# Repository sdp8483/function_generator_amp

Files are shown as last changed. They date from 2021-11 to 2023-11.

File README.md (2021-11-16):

# KiCAD Directory Structure

Directory structure for starting new projects in KiCAD. Based off Hackaday article: https://hackaday.com/2017/05/18/kicad-best-practises-library-management/

## Directory Outline
- [`~/pcb/`](pcb) is for KiCAD desinge files. When starting a new KiCAD project in this directory be sure to uncheck *Create a new direcotry for the project* in the **Create New Project** window.
- [`~/firmware/`](firmware) is for firmware souce code and binaries.
- [`~/enclosure/`](enclosure) is for mechanical CAD design files for the encloser or box. Create seperate directories for `.stl` or other files for 3d printing for easy accesss.

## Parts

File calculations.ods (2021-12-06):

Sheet: General
Function Generator Amplifier Calculaitons
based on the following design guide: https://www.circuitbasics.com/tda2050-diy-amplifier-build-guide/
TDA2030 Limits
Minumum Gain | 24 | dB
Supply Voltage | ±18 | V | 36
Peak Output Current | 3.5 | A
Max Power Dissipation | 20 | W
Desired Output
Output Voltage | 10 | Vrms
Output Voltage | 28.3 | Vp-p
Peak Output Voltage
Load Impedance, Rl | 75 | Ω
Power Output Average, Po | 7.66139999998758 | W
Peak Output Voltage, Vp | 33.9 | V
Maximum Supply Voltage Needed by the Amplifier
Peak Output Voltage, Vp | 33.9 | V
TDA2030 Voltage Drop, Vd | 4 | V
Xformer Voltage Increase when unloaded, Vr | 6%
Variation in mains voltage, Vvm | 10%
Max Supply Voltage, Vs | 44.2 | V
Maximum Supply Voltage Provided by a Transformer
Transformer Voltage Rating, Vt | 12 | VAC
Rectified Voltage Increse Factor, Vd | 1.41
Variation in mains voltage, Vvm | 10%
Xformer Voltage Increase when unloaded, Vr | 6%
Maximum Supply Voltage, Vs | 19.7 | V
Amplifier Output Power from a Transformers Maximum Supply Voltage
Output Power, Po | 1.1 | W
Maximum xformer supply voltage, Vcc | 19.7 | V
TDA2030 Voltage Drop, Vd | 4 | V
Xformer Voltage Increase when unloaded, Vr | 6%
Variation in mains voltage, Vvm | 10%
Load Impedance, Rl | 75 | Ω
Transformer Power Needed by the Amplifier
Maximum xformer supply voltage, Vcc | 19.7 | V
Peak Output Voltage, Vp | 33.9 | V
TDA2030 Quiescent draion current, Iq | 0.06 | A
Load Impedance, Rl | 75 | Ω
Total Power, Psupply | 8.0 | W
Transformer VA Rating
Rating Factor | 1.5
Transformer VA | 12.1 | VA
Maximum Power Dissipation
Maximum xformer supply voltage, Vcc | 19.7 | V
Load Impedance, Rl | 75 | Ω
Max Power Dissipation, Pd | 1.1 | W
Maximum Thermal Resistance of the Heat Sink
Max Junction Temperature, Tjmax | 150 | C
Ambient Temperature, Tamb | 25 | C
Junction to Case thermal resistance, Rjc | 3 | C/W
Case to heatsink thermal resistance, Rch | 0.12 | C/W
Max Power Dissipation, Pd | 1.1 | W
Max Thermal Resistance of the Heat Sink, Rh | 115.7 | C/W

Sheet: Transformer
Transformer Settings
Output Voltage | 20 | VAC
Output Rating | 20 | VA
Unloaded Voltage | 12%
Power Factor | 1.5
Calculated Max Power | 13.3 | W
Rectified Voltage
Rectifcation Factor | 1.41
Mains Voltage Variation | 10%
Max Rectified Voltage | 34.8 | VDC
 | 17.4 | ±VDC
Ripple Voltage
Max Load Current | 1.5 | A
Mains Frequeuncy | 60 | Hz
Total Capacitance Per Rail | 6600 | uF
Ripple Voltage | 1.89 | V

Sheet: Amplifier
Minimum Gain |  |  |  | SI Prefixes
Input Voltage, Vin | 0.5 | V |  | symbol | 10^n
Load Impedance | 6 | Ω |  | k | 1000
Output Power | 14 | W |  | m | 0.001
Gain | 18.3 |  |  | μ | 0.000001
Gain, db | 25.3 | db |  | n | 0.000000001
 |  |  |  | p | 1E-12
Gain
R3 | 22 | kΩ
R2 | 1000 | Ω
Gain | 23.0 | V/V
 | 27.2 | dB
Input Signal | 0.184 | V
Output Signal | 4.243 | V
 | 6.000 | Vrms
Balance Input Bias Current
R12 | 1 | kΩ
R1 | 21 | kΩ
R3 | 22 | kΩ
R3 : (R1 + R3) | 1
Input High Pass Filter
C5 | 2.2 | uF
R1 | 21 | kΩ
Cutoff Frequency, Fc | 3.4 | Hz
Feedback Loop High Pass Filter
R2 | 1000 | Ω
C6 | 220 | uF
Cutoff Frequency, Fc | 0.7 | Hz
Input to Feedback Fc Ratio | 4.8
Input Low Pass Filter
R11 | 1 | kΩ
R12 | 1 | kΩ
C19 | 220 | pF
Cutoff Frequency, Fc | 362 | kHz
Zorbel Network |  |  | c
R4 | 10 | Ω
C11 | 100 | nF
Cutoff Frequency, Fc | 159 | kHz

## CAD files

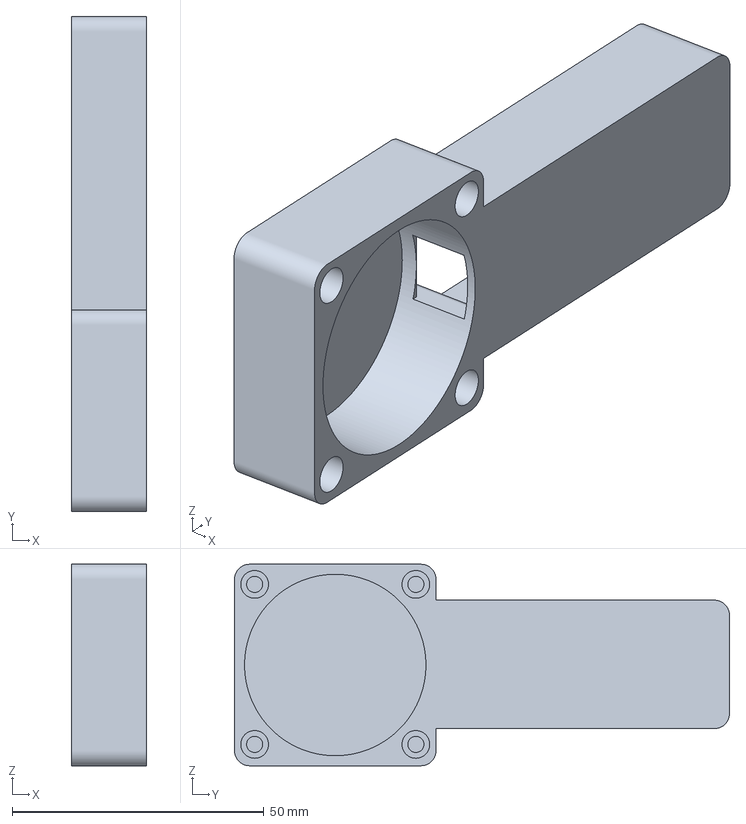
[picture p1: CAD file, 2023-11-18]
enclosure/files_to_print/func_amp-printed_shroud_V2.amf
14.9 x 98.2 x 40.0 mm

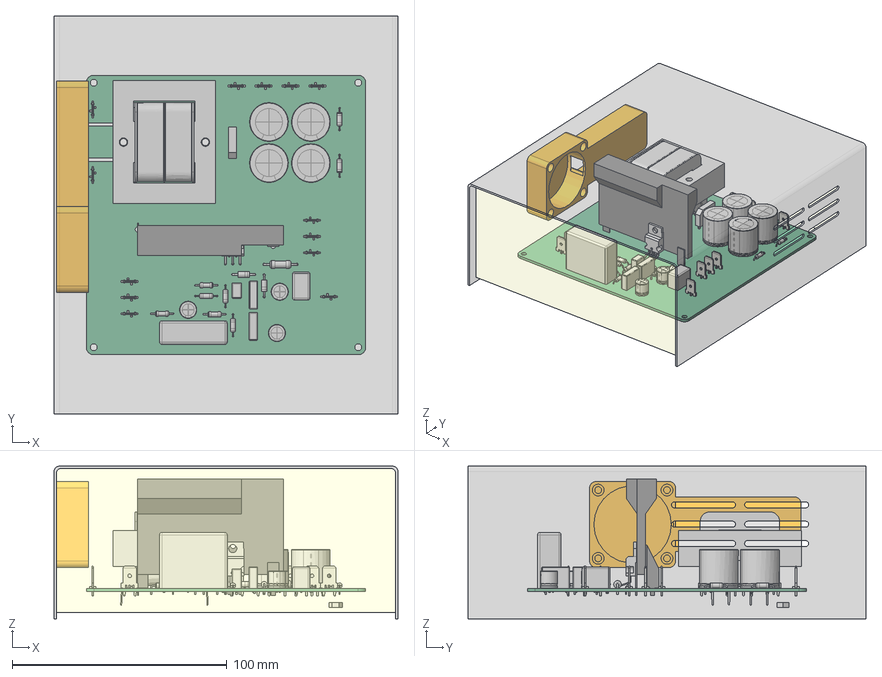
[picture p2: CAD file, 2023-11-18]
enclosure/func_amp.FCStd
160.0 x 185.0 x 71.0 mm
Pcb_d66f
C5_C_Rect_L315mm_W110mm_P2750mm_MKS4_00006199bca8
C6_CP_Radial_D80mm_P380mm_00006199bd2c x 3
C9_C_Rect_L130mm_W40mm_P1000mm_FKS3_FKP3_MKS4_00006199bed8 x 2
C11_C_Rect_L130mm_W80mm_P1000mm_FKS3_FKP3_MKS4_00006199bfe0
D3_D_DO-41_SOD81_P10.16mm_Horizontal_00006199c03d x 2
R1_R_Axial_DIN0207_L63mm_D25mm_P1016mm_Horizontal_00006199c0e7 x 8
R4_R_Axial_DIN0411_L99mm_D36mm_P1524mm_Horizontal_00006199c12c
U3_TO_220_5_Pentawatt_Multiwatt_5_Vertical_StaggeredType1_00006199c99d
C19_C_Rect_L72mm_W45mm_P500mm_FKS2_FKP2_MKS2_MKP2_000061b01abd
HS1_random_psu_heatsink_000061b53a8c
C1_CP_Radial_D180mm_P750mm_000061b6361c x 4
T1_ST-6-20_sp_000061b6451d
J1_TE_63824-1_000061b6cb5c x 13
D1_KBP10G_000061b6e6a1[2]
top
bottom
mount
shround V2
M3 Nut
fan

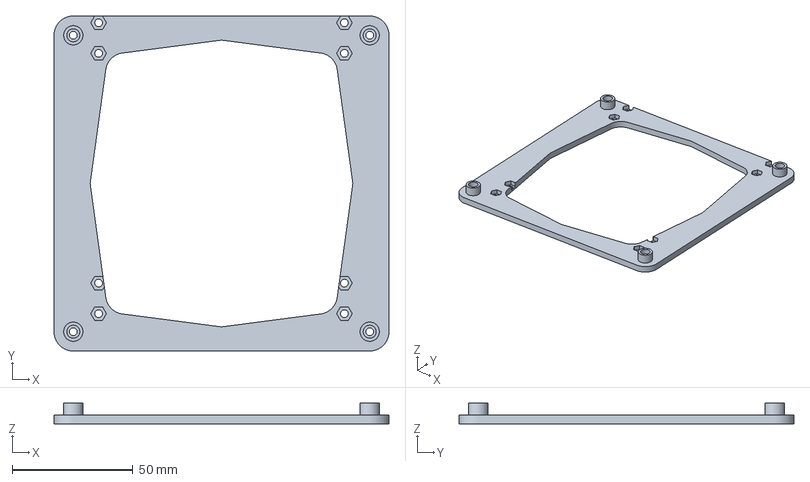
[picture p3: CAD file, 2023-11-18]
enclosure/files_to_print/func_amp-printed_mount_V2.amf
139.0 x 139.0 x 8.60 mm

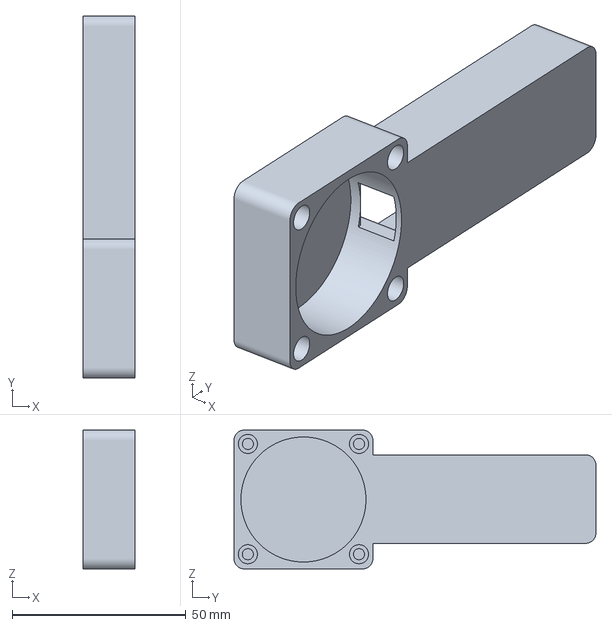
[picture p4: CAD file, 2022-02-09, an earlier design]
enclosure/files_to_print/func_amp-printed_shroud.amf
14.9 x 104.2 x 40.0 mm

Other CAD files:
enclosure/files_to_print/func_amp-printed_mount.amf

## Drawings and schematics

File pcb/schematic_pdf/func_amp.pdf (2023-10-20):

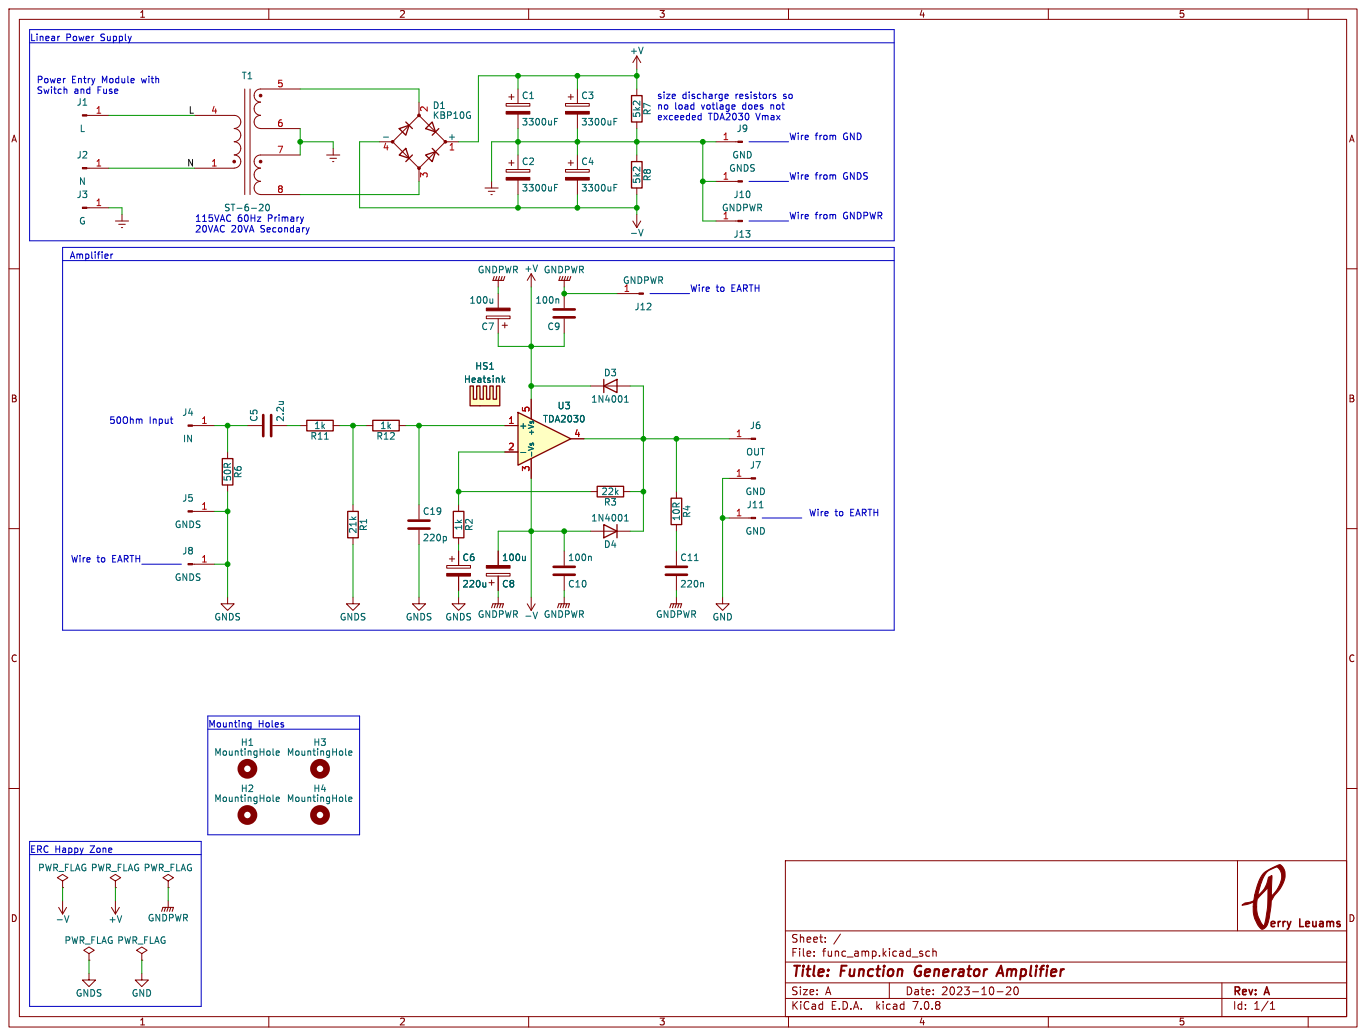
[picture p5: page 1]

no load votlage does not exceeded TDA2030 Vmax Linear Power Supply

Power Entry Module with Switch and Fuse

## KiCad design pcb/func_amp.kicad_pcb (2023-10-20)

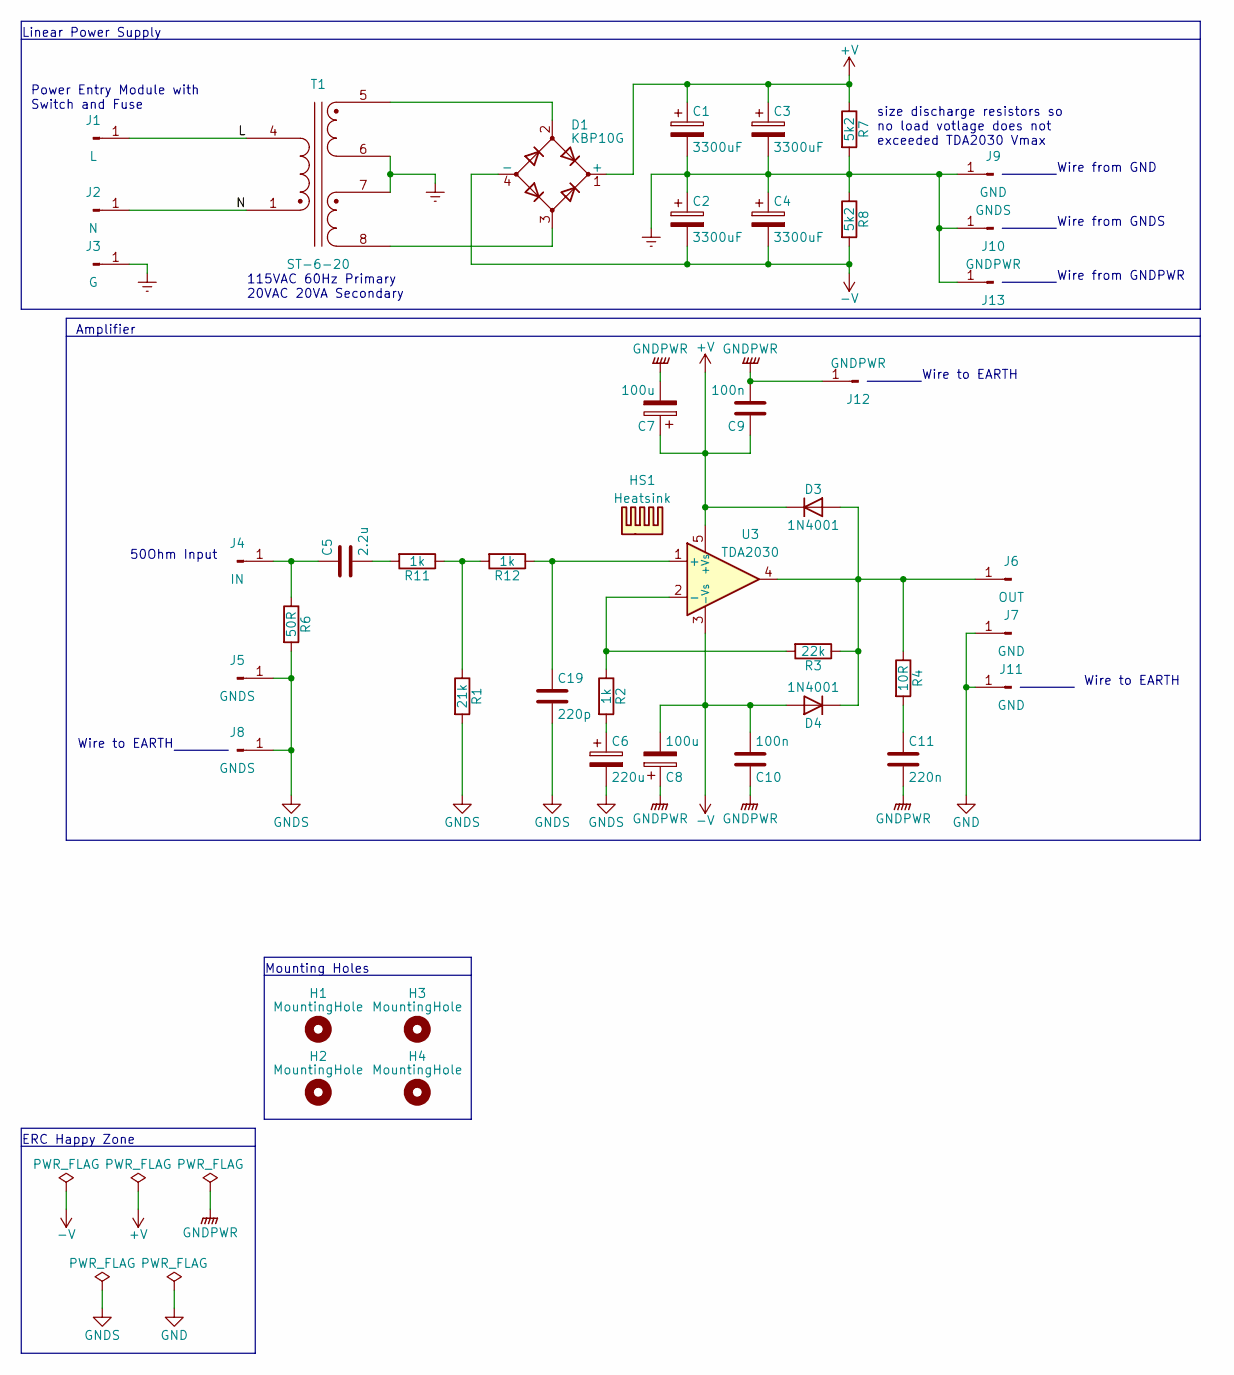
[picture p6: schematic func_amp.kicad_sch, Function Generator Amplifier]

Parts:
C1, C2, C3, C4: 3300uF; CP_Radial_D18.0mm_P7.50mm
C5: 2.2u; C_Rect_L31.5mm_W11.0mm_P27.50mm_MKS4
C6: 220u; CP_Radial_D8.0mm_P3.80mm
C7, C8: 100u; CP_Radial_D8.0mm_P3.80mm
C9, C10: 100n; C_Rect_L13.0mm_W4.0mm_P10.00mm_FKS3_FKP3_MKS4
C11: 220n; C_Rect_L13.0mm_W8.0mm_P10.00mm_FKS3_FKP3_MKS4
C19: 220p; C_Rect_L7.2mm_W4.5mm_P5.00mm_FKS2_FKP2_MKS2_MKP2
D1: KBP10G; Diode_Bridge_Vishay_KBPM
D3, D4: 1N4001; D_DO-41_SOD81_P10.16mm_Horizontal
H1, H2, H3, H4: MountingHole; MountingHole_3.2mm_M3
HS1: Heatsink; random_psu_heatsink
J1: L; TE_0.25in_spade_63824-1
J2: N; TE_0.25in_spade_63824-1
J3: G; TE_0.25in_spade_63824-1
J4: IN; TE_0.25in_spade_63824-1
J5, J8, J10: GNDS; TE_0.25in_spade_63824-1
J6: OUT; TE_0.25in_spade_63824-1
J7, J9, J11: GND; TE_0.25in_spade_63824-1
J12, J13: GNDPWR; TE_0.25in_spade_63824-1
R1: 21k; R_Axial_DIN0207_L6.3mm_D2.5mm_P10.16mm_Horizontal
R2, R11, R12: 1k; R_Axial_DIN0207_L6.3mm_D2.5mm_P10.16mm_Horizontal
R3: 22k; R_Axial_DIN0207_L6.3mm_D2.5mm_P10.16mm_Horizontal
R4: 10R; R_Axial_DIN0411_L9.9mm_D3.6mm_P15.24mm_Horizontal
R6: 50R; R_Axial_DIN0207_L6.3mm_D2.5mm_P10.16mm_Horizontal
R7, R8: 5k2; R_Axial_DIN0207_L6.3mm_D2.5mm_P10.16mm_Horizontal
T1: ST-6-20
U3: TDA2030; TO-220-5_P3.4x3.7mm_StaggerOdd_Lead3.8mm_Vertical

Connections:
+V: C1.1, C3.1, C7.1, C9.1, D1.1 (+), D3.1 (K), R7.1, U3.5 (+Vs)
-V: C2.2, C4.2, C8.2, C10.2, D1.4 (-), D4.2 (A), R8.2, U3.3 (-Vs)
/L: J1.1, T1.4 (AB)
/N: J2.1, T1.1 (AA)
Earth: C1.2, C2.1, C3.2, C4.1, J3.1, J9.1, J10.1, J13.1, R7.2, R8.1, T1.6 (SB), T1.7 (SC)
GND: J7.1, J11.1
GNDPWR: C7.2, C8.1, C9.2, C10.1, C11.2, J12.1
GNDS: C6.2, C19.2, J5.1, J8.1, R1.2, R6.2
unnamed: C5.1, J4.1, R6.1
unnamed: C5.2, R11.2
unnamed: C6.1, R2.2
unnamed: C11.1, R4.2
unnamed: C19.1, R12.1, U3.1 (+)
unnamed: D1.2, T1.5 (SA)
unnamed: D1.3, T1.8 (SD)
unnamed: D3.2 (A), D4.1 (K), J6.1, R3.1, R4.1, U3.4
unnamed: R1.1, R11.1, R12.2
unnamed: R2.1, R3.2, U3.2 (-)

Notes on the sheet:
Linear Power Supply
size discharge resistors so no load votlage does not exceeded TDA2030 Vmax
Amplifier
Wire to EARTH
Mounting Holes
Wire from GNDPWR
ERC Happy Zone
115VAC 60Hz Primary 20VAC 20VA Secondary
Power Entry Module with Switch and Fuse
50Ohm Input
Wire from GND
Wire from GNDS

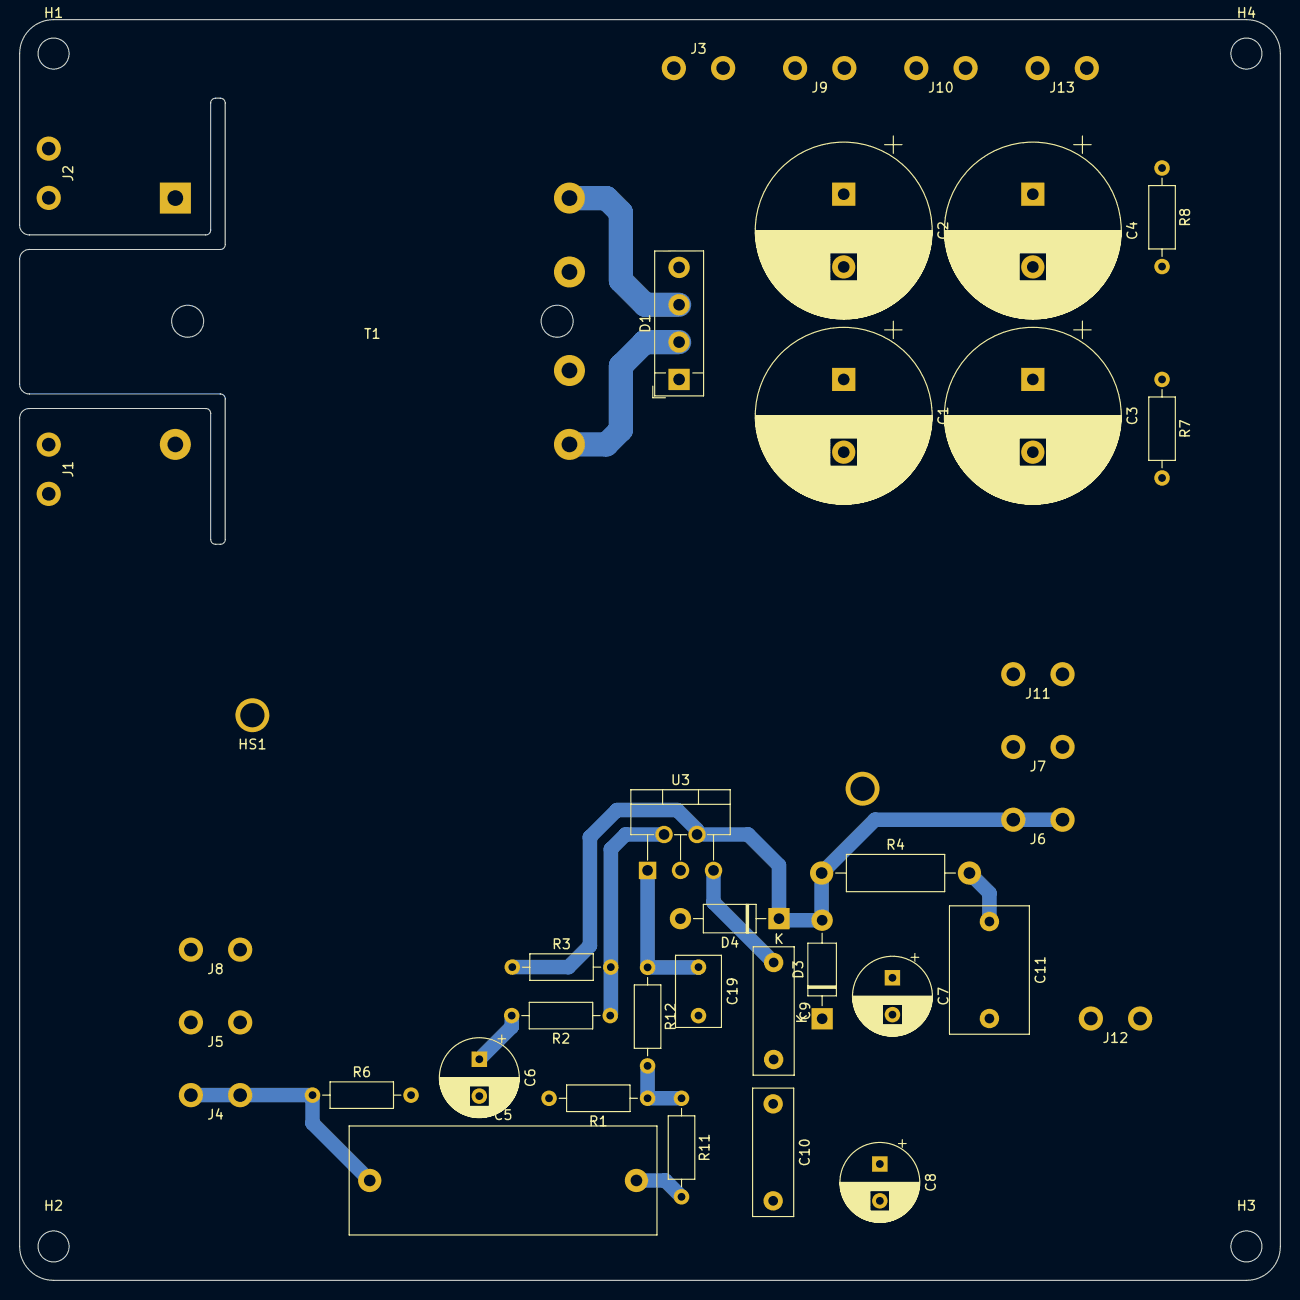
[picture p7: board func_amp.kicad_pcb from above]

Board: 2 copper layers, 130.0 x 130.0 mm, 44 parts (0 on the bottom side), 18 nets.

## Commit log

2021-11-21 init pcb layout and gerber
    [func_amp.kicad_pcb, func_amp.sch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]
2021-11-21 create ibom
    [func_amp.kicad_pcb]
2021-11-24 update with available component value
    [func_amp.sch]
2021-12-06 update schema
    [func_amp.sch]
2021-12-08 update footprints
    [func_amp.kicad_pcb, func_amp.sch]
2021-12-12 create heatsink model
2021-12-12 add heatsink
    [func_amp.sch]
2021-12-12 spade grounds for star ground
    [func_amp.sch]
2021-12-13 spade star grounds
    [func_amp.sch]
2021-12-13 pcb layout
    [func_amp.kicad_pcb]
2021-12-19 new gerbers
    [func_amp-B_Cu.gbr, func_amp-Edge_Cuts.gbr, func_amp-job.gbrjob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]
2022-01-30 update to KiCAD V6
    [func_amp.kicad_pcb, func_amp.kicad_sch]
2022-02-09 fix shroud
    [func_amp-printed_shroud.amf, func_amp.FCStd]
2023-10-20 cleanup schematic
    [func_amp.kicad_sch]
2023-10-20 update gerbers
    [func_amp.kicad_pcb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]
2023-11-18 printed parts dim changes
    [func_amp-printed_mount_V2.amf, func_amp-printed_shroud_V2.amf, func_amp.FCStd]
